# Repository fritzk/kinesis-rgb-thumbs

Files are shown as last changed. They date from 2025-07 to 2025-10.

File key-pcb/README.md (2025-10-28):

# Single-Switch SMD RGB PCB
A compact PCB designed to add individual, addressable SMD RGB lighting to a single mx mechanical keyboard switch.

---

## Features

* **Compact Footprint:** Minimal size, smaller than 1U
* **Chainable:** Data in/out for LED on either side of board
* **Addressable RGB:** Designed for **SK6812MINI-E** leds 

---

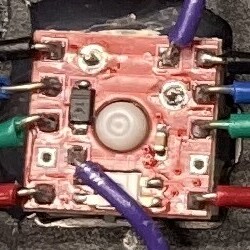
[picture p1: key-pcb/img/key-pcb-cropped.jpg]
A cropped preview of the image


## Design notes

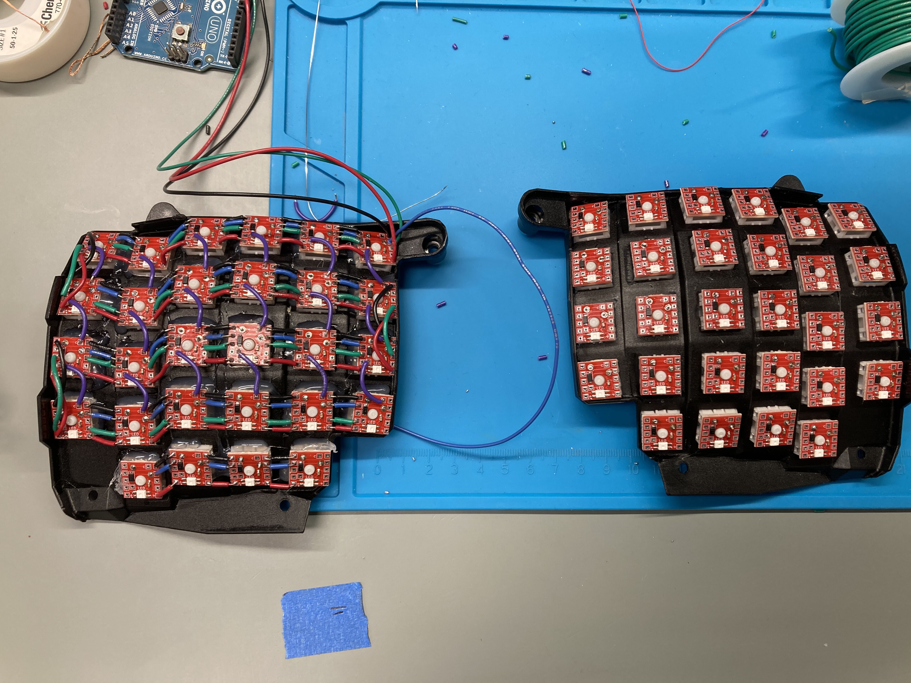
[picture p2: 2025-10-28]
key-pcb/img/key-pcb.jpg

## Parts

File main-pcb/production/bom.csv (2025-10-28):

Designator | Footprint | Quantity | Value | LCSC Part #
H1 | MountingHole_4.3mm_M4_Pad | 1 | mounting pad
J1, J2 | Molex_0039532135 | 2 | Conn_01x13
J10 | PinSocket_1x04_P2.54mm_Vertical | 1 | Conn_01x04
J3 | Molex_KK-254_AE-6410-06A_1x06_P2.54mm_Vertical | 1 | Conn_01x06
J4 | Molex_KK-254_AE-6410-06A_1x06_P2.54mm_Vertical | 1 | Conn_01x06_Pin
J5 | Molex_KK-254_AE-6410-09A_1x09_P2.54mm_Vertical | 1 | Conn_01x09
J6 | Molex_KK-254_AE-6410-09A_1x09_P2.54mm_Vertical | 1 | Conn_01x09_Pin
J7, J8 | PinHeader_1x10_P2.54mm_Vertical | 2 | Conn_01x10_Pin
J9 | PinHeader_1x01_P1.00mm_Vertical | 1 | Conn_01x01
M1 | MountingHole_6.4mm_M6 | 1 | MountingHole_6.4mm_M6
Q1 | SOT-23 | 1 | BSS138
R1, R2 | 0805 | 2 | 10K
U1 | ElitePi | 1 | Elite-Pi

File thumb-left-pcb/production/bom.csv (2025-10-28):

Designator | Footprint | Quantity | Value | LCSC Part #
C25, C35, C36, C46, C55, C56 | 0805 | 6 | 0.1 µF
D25, D35, D36, D46, D55, D56 | D_SOD-123F | 6 | 1N4148WL
J1 | PinHeader_1x10_P2.54mm_Vertical | 1 | Conn_01x10
LED25, LED35, LED36, LED46, LED55, LED56 | LED_MX_6028R | 6 | MX_SK6812MINI-E
MX25, MX35, MX55, MX56 | SW_Cherry_MX_PCB_1.00u | 4 | MX_SW_HS
MX36, MX46 | SW_Cherry_MX_PCB_2.00u_90deg | 2 | MX_SW_HS

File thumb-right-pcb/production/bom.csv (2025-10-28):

Designator | Footprint | Quantity | Value | LCSC Part #
C65, C66, C75, C85, C86, C96 | 0805 | 6 | 0.1 µF
D65, D66, D75, D85, D86, D96 | D_SOD-123F | 6 | 1N4148WL
J1 | PinHeader_1x10_P2.54mm_Vertical | 1 | Conn_01x10
LED65, LED66, LED75, LED85, LED86, LED96 | LED_MX_6028R | 6 | MX_SK6812MINI-E
MX65, MX75 | SW_Cherry_MX_PCB_2.00u_90deg | 2 | MX_SW_HS
MX66, MX85, MX86, MX96 | SW_Cherry_MX_PCB_1.00u | 4 | MX_SW_HS

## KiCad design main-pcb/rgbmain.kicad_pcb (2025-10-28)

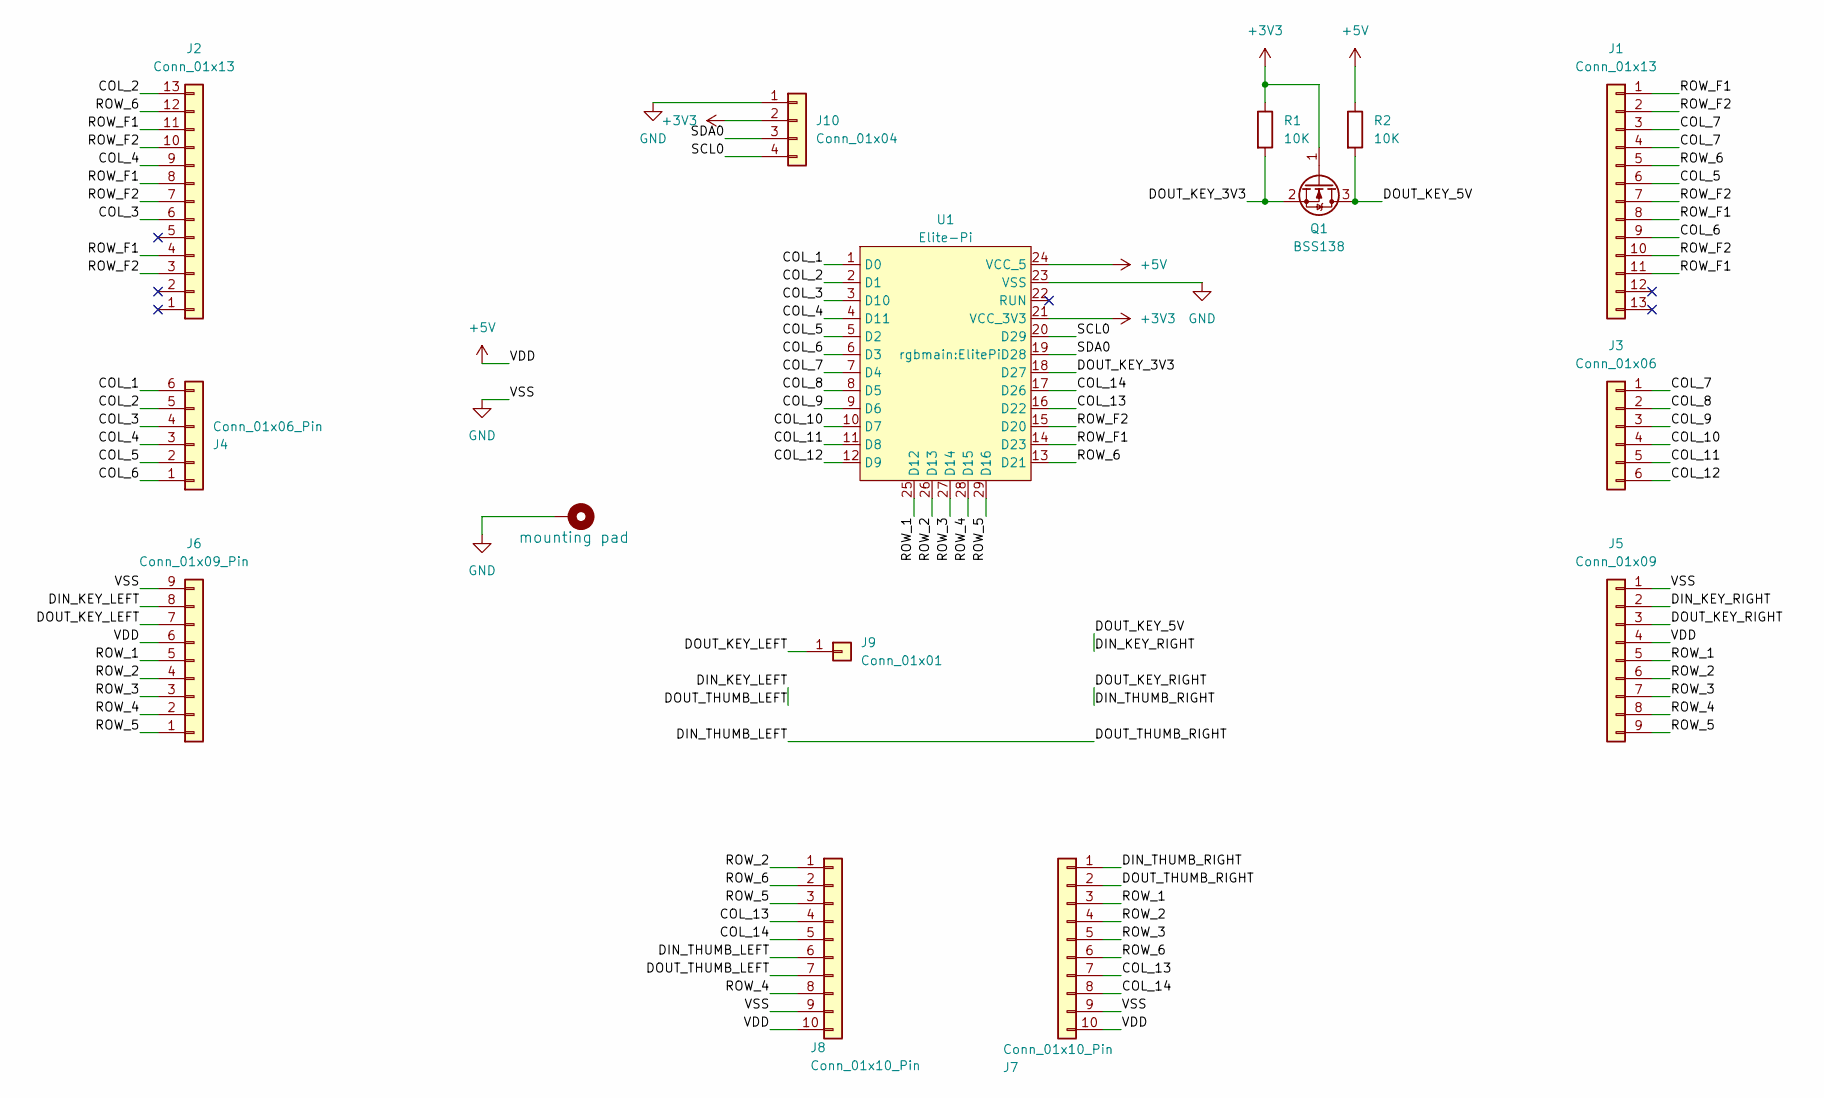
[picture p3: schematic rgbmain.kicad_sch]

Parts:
H1: mounting pad; MountingHole_4.3mm_M4_Pad
J1, J2: Conn_01x13; Molex_0039532135
J3: Conn_01x06; Molex_KK-254_AE-6410-06A_1x06_P2.54mm_Vertical
J4: Conn_01x06_Pin; Molex_KK-254_AE-6410-06A_1x06_P2.54mm_Vertical
J5: Conn_01x09; Molex_KK-254_AE-6410-09A_1x09_P2.54mm_Vertical
J6: Conn_01x09_Pin; Molex_KK-254_AE-6410-09A_1x09_P2.54mm_Vertical
J7, J8: Conn_01x10_Pin; PinHeader_1x10_P2.54mm_Vertical
J9: Conn_01x01; PinHeader_1x01_P1.00mm_Vertical
J10: Conn_01x04; PinSocket_1x04_P2.54mm_Vertical
Q1: BSS138; SOT-23
R1, R2: 10K; R_0805_2012Metric_Pad1.20x1.40mm_HandSolder
U1: Elite-Pi; ElitePi

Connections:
+3V3: J10.2, Q1.1 (G), R1.1, U1.21 (VCC_3V3)
+5V: J5.4, J6.6, J7.10, J8.10, R2.1, U1.24 (VCC_5)
/COL_1: J4.6, U1.1 (D0)
/COL_2: J2.13, J4.5, U1.2 (D1)
/COL_3: J2.6, J4.4, U1.3 (D10)
/COL_4: J2.9, J4.3, U1.4 (D11)
/COL_5: J1.6, J4.2, U1.5 (D2)
/COL_6: J1.9, J4.1, U1.6 (D3)
/COL_7: J1.3, J1.4, J3.1, U1.7 (D4)
/COL_8: J3.2, U1.8 (D5)
/COL_9: J3.3, U1.9 (D6)
/COL_10: J3.4, U1.10 (D7)
/COL_11: J3.5, U1.11 (D8)
/COL_12: J3.6, U1.12 (D9)
/COL_13: J7.7, J8.4, U1.16 (D22)
/COL_14: J7.8, J8.5, U1.17 (D26)
/DIN_KEY_LEFT: J6.8, J8.7
/DIN_KEY_RIGHT: J5.2, Q1.3 (D), R2.2
/DIN_THUMB_LEFT: J7.2, J8.6
/DIN_THUMB_RIGHT: J5.3, J7.1
/DOUT_KEY_3V3: Q1.2 (S), R1.2, U1.18 (D27)
/DOUT_KEY_LEFT: J6.7, J9.1
/ROW_1: J5.5, J6.5, J7.3, U1.25 (D12)
/ROW_2: J5.6, J6.4, J7.4, J8.1, U1.26 (D13)
/ROW_3: J5.7, J6.3, J7.5, U1.27 (D14)
/ROW_4: J5.8, J6.2, J8.8, U1.28 (D15)
/ROW_5: J5.9, J6.1, J8.3, U1.29 (D16)
/ROW_6: J1.5, J2.12, J7.6, J8.2, U1.13 (D21)
/ROW_F1: J1.1, J1.8, J1.11, J2.4, J2.8, J2.11, U1.14 (D23)
/ROW_F2: J1.2, J1.7, J1.10, J2.3, J2.7, J2.10, U1.15 (D20)
/SCL0: J10.4, U1.20 (D29)
/SDA0: J10.3, U1.19 (D28)
GND: H1.1, J5.1, J6.9, J7.9, J8.9, J10.1, U1.23 (VSS)

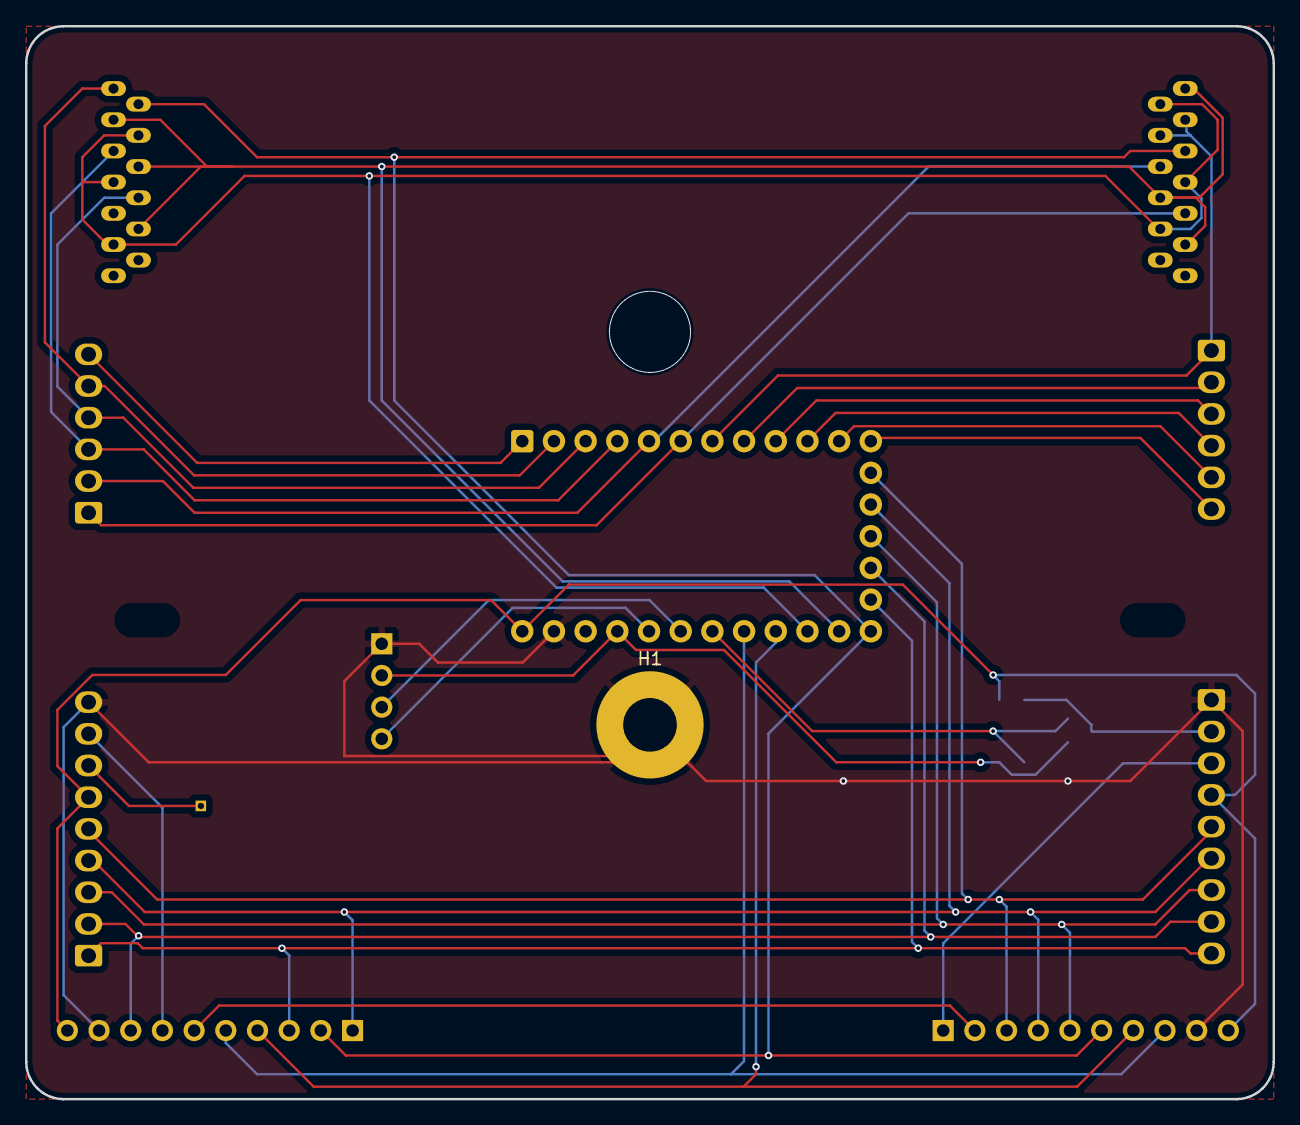
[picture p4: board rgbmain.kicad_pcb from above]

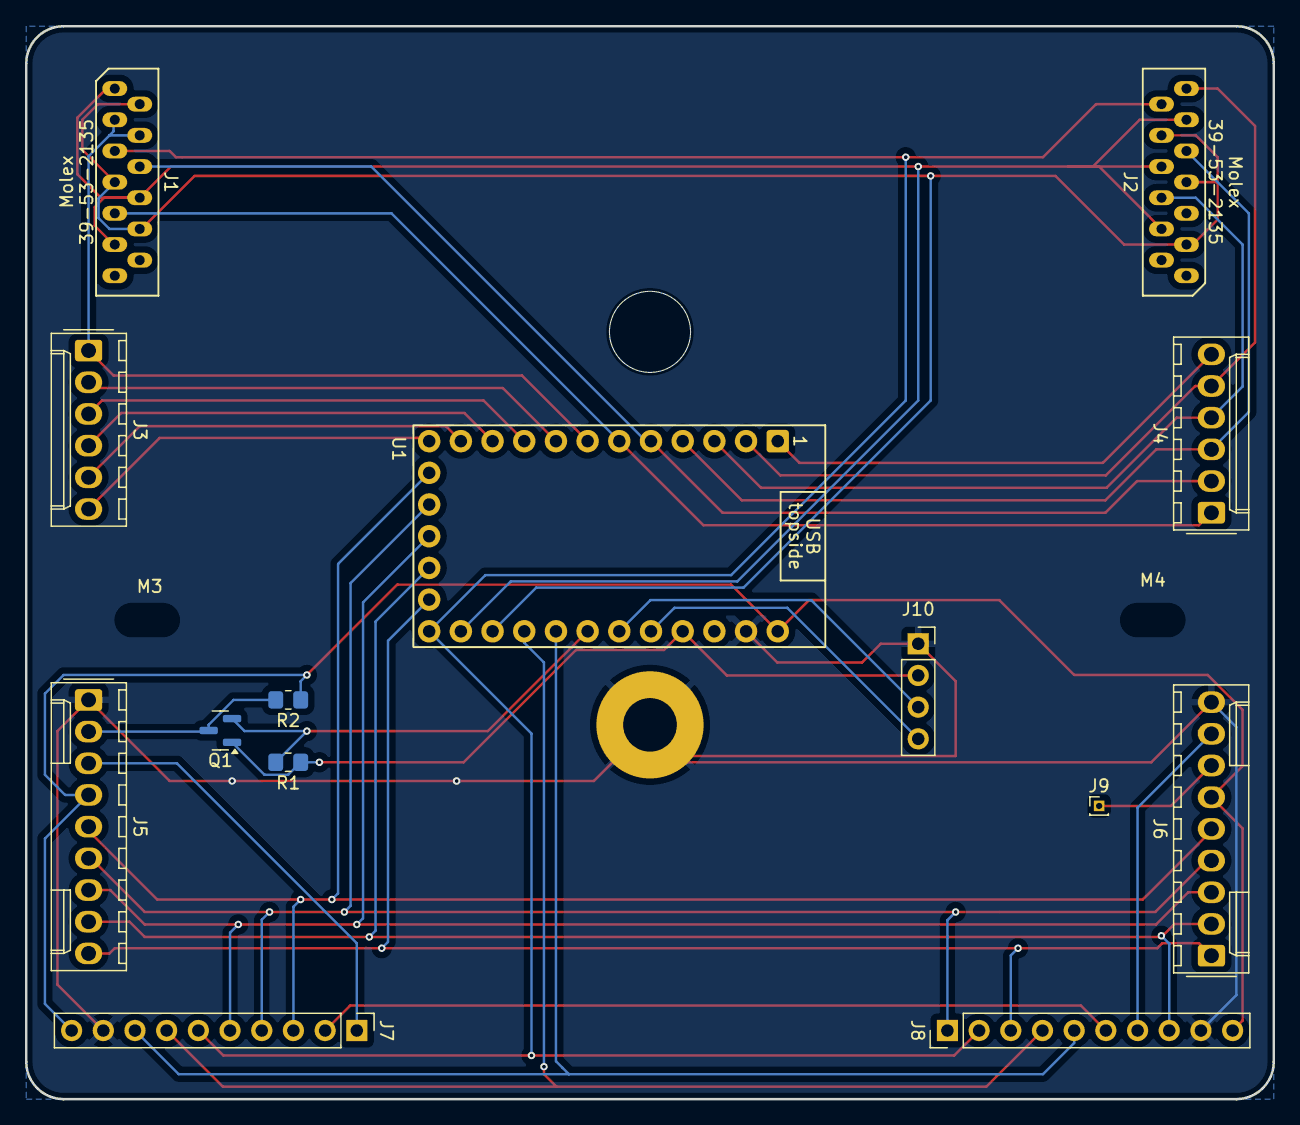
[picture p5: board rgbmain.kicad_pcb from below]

Board: 2 copper layers, 100.0 x 86.0 mm, 18 parts (17 on the bottom side), 33 nets.

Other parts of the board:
M1: MountingHole_6.4mm_M6
M3, M4: MountingHole_4.3mm_M4

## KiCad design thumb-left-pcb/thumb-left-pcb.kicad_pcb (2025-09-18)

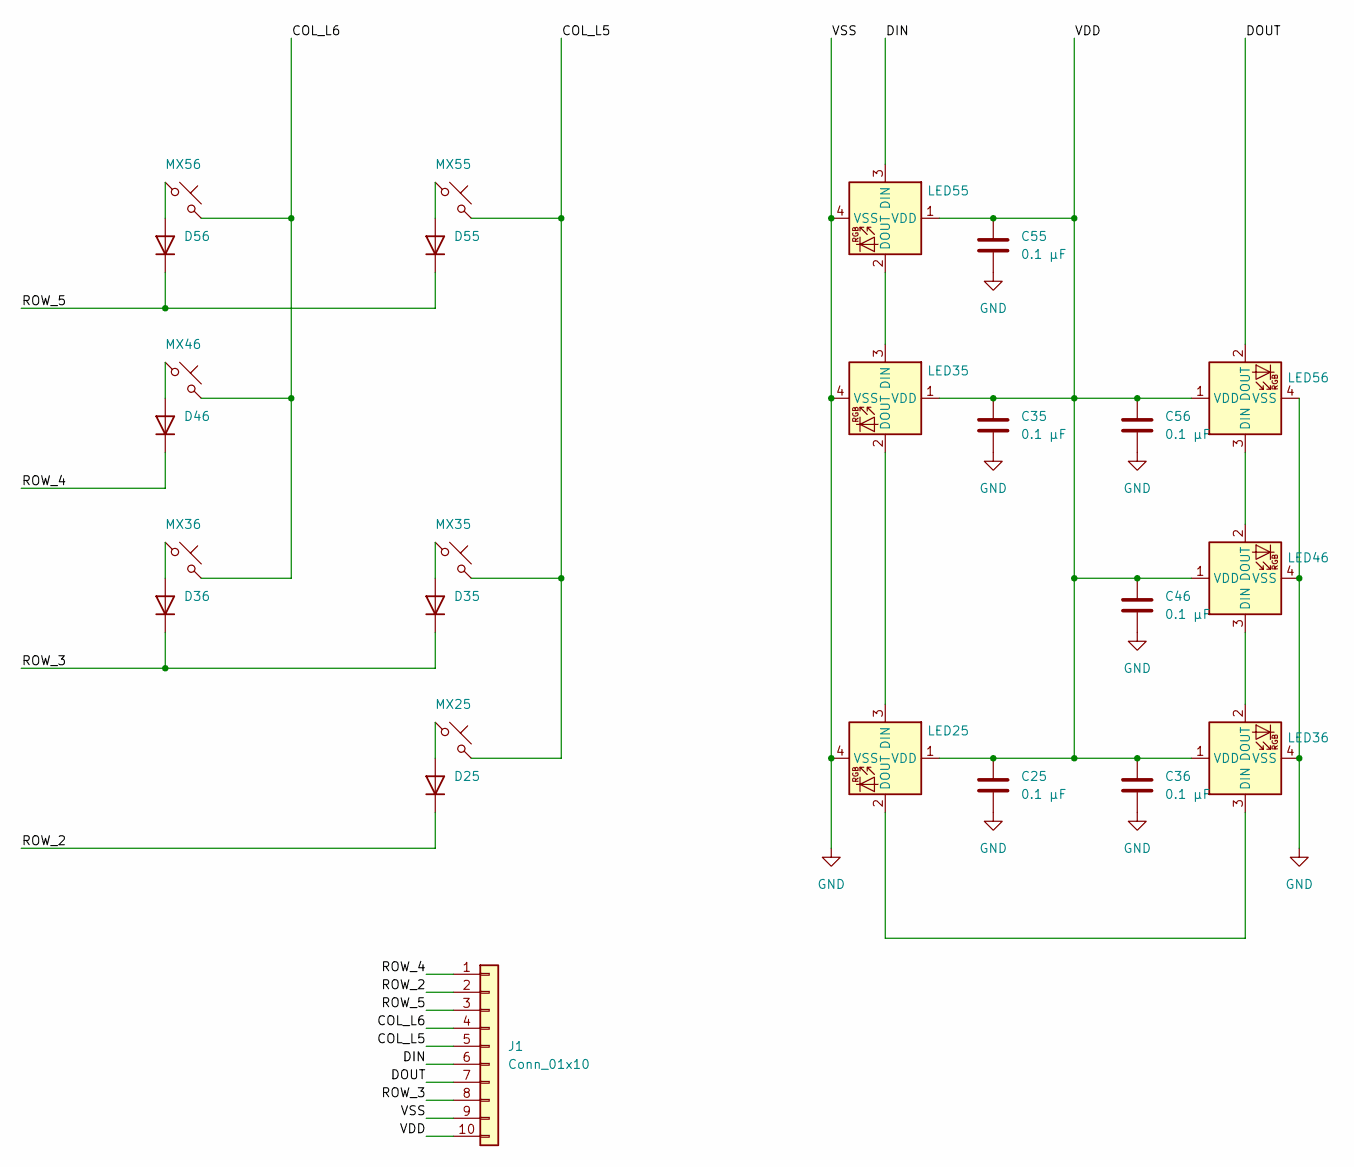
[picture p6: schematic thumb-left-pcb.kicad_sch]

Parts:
C25, C35, C36, C46, C55, C56: 0.1 µF; C_0805_2012Metric_Pad1.18x1.45mm_HandSolder
D25, D35, D36, D46, D55, D56: 1N4148WL; D_SOD-123F
J1: Conn_01x10; PinHeader_1x10_P2.54mm_Vertical
LED25, LED35, LED36, LED46, LED55, LED56: MX_SK6812MINI-E; LED_MX_6028R
MX25, MX35, MX55, MX56: MX_SW_HS; SW_Cherry_MX_PCB_1.00u
MX36, MX46: MX_SW_HS; SW_Cherry_MX_PCB_2.00u_90deg

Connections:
/COL_L5: J1.5, MX25.2, MX35.2, MX55.2
/COL_L6: J1.4, MX36.2, MX46.2, MX56.2
/DIN: J1.6, LED55.3 (DIN)
/DOUT: J1.7, LED56.2 (DOUT)
/ROW_2: D25.1 (K), J1.2
/ROW_3: D35.1 (K), D36.1 (K), J1.8
/ROW_4: D46.1 (K), J1.1
/ROW_5: D55.1 (K), D56.1 (K), J1.3
/VDD: C25.1, C35.1, C36.1, C46.1, C55.1, C56.1, J1.10, LED25.1 (VDD), LED35.1 (VDD), LED36.1 (VDD), LED46.1 (VDD), LED55.1 (VDD), LED56.1 (VDD)
GND: C25.2, C35.2, C36.2, C46.2, C55.2, C56.2, J1.9, LED25.4 (VSS), LED35.4 (VSS), LED36.4 (VSS), LED46.4 (VSS), LED55.4 (VSS), LED56.4 (VSS)
unnamed: D25.2 (A), MX25.1
unnamed: D35.2 (A), MX35.1
unnamed: D36.2 (A), MX36.1
unnamed: D46.2 (A), MX46.1
unnamed: D55.2 (A), MX55.1
unnamed: D56.2 (A), MX56.1
unnamed: LED25.3 (DIN), LED35.2 (DOUT)
unnamed: LED25.2 (DOUT), LED36.3 (DIN)
unnamed: LED35.3 (DIN), LED55.2 (DOUT)
unnamed: LED36.2 (DOUT), LED46.3 (DIN)
unnamed: LED46.2 (DOUT), LED56.3 (DIN)

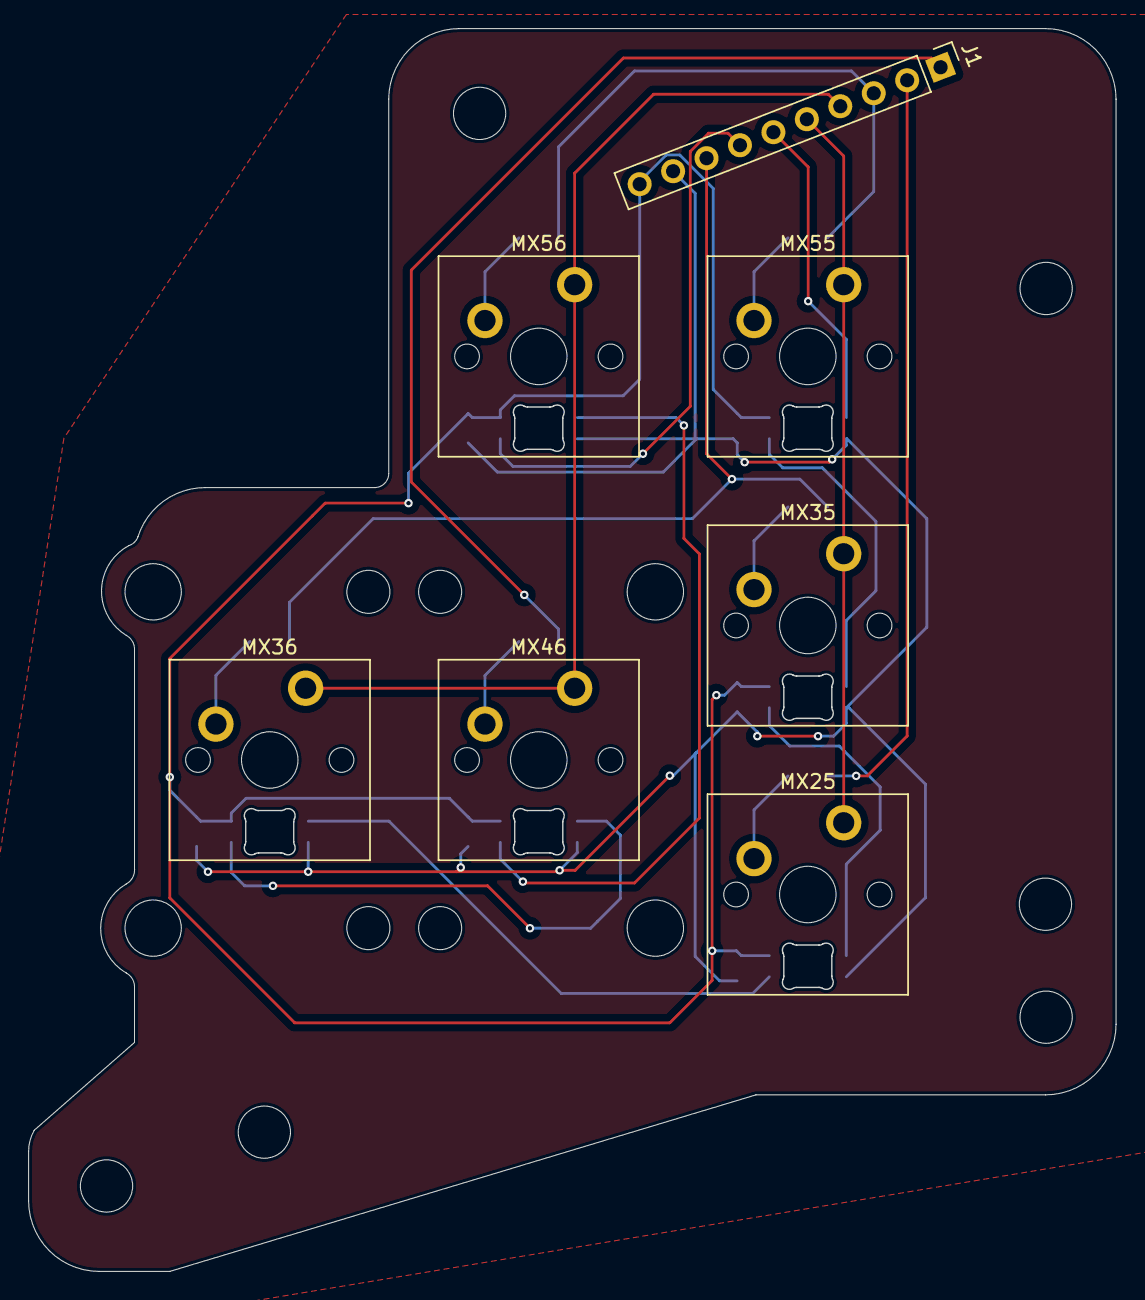
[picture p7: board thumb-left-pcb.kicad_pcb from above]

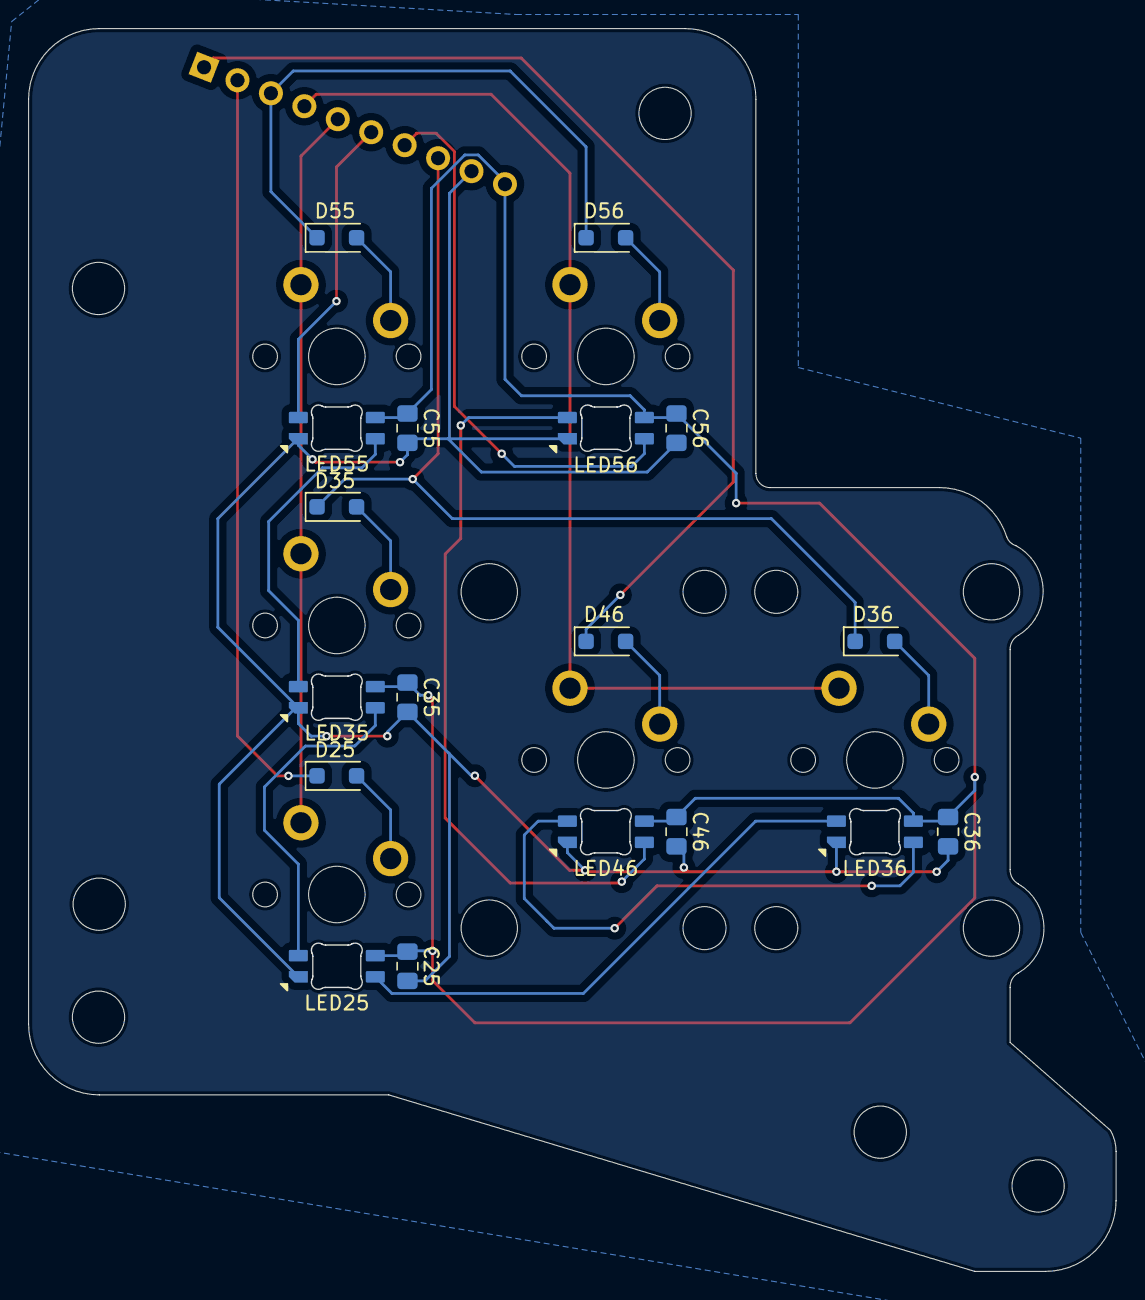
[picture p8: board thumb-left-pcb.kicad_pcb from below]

Board: 2 copper layers, 77.0 x 88.0 mm, 31 parts (18 on the bottom side), 21 nets.

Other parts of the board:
REF1, REF2, REF3, REF4, REF5, REF6: MountingHole_3.7mm

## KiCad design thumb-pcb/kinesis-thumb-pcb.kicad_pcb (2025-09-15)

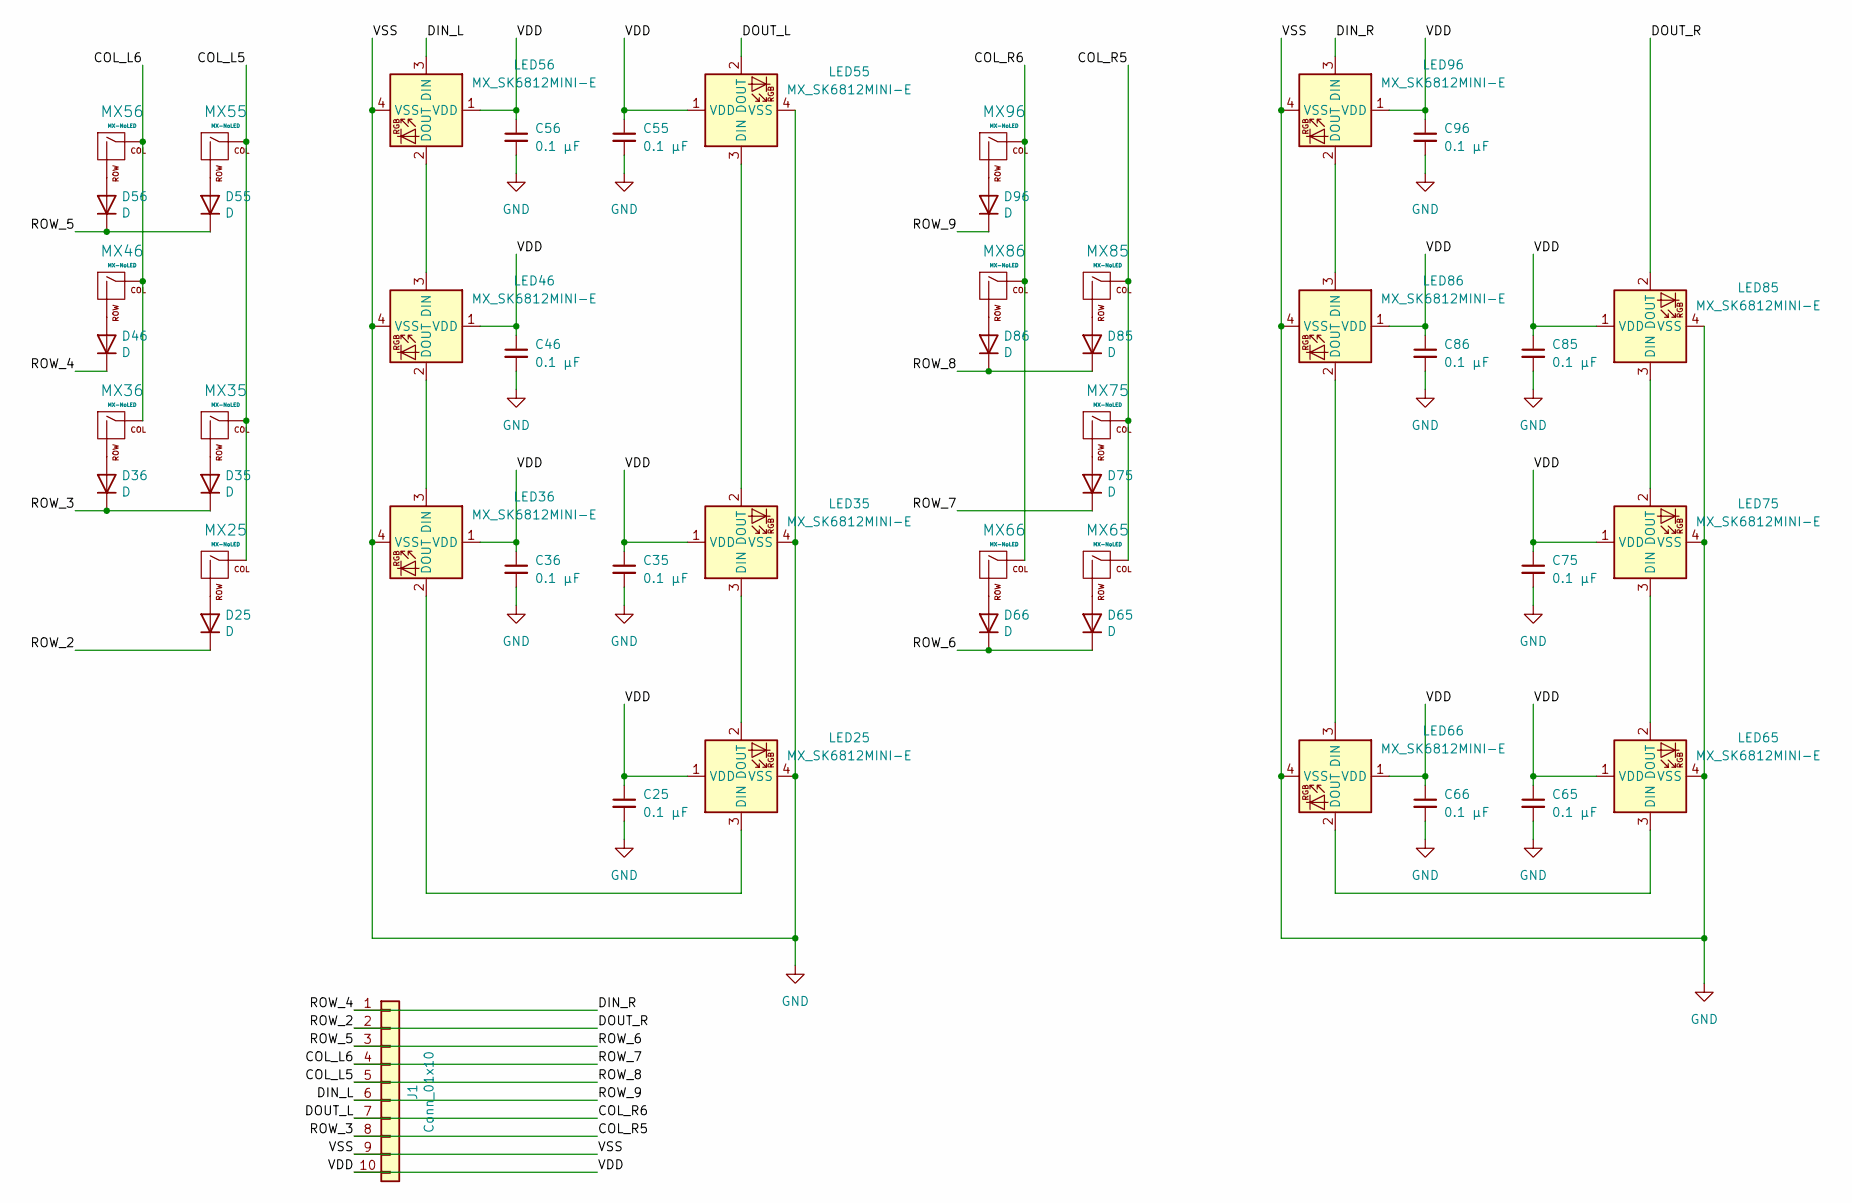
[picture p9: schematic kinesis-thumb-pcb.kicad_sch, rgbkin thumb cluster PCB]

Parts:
C25, C35, C36, C46, C55, C56, C65, C66, C75, C85, C86, C96: 0.1 µF; C_0805_2012Metric_Pad1.18x1.45mm_HandSolder
D25, D35, D36, D46, D55, D56, D65, D66, D75, D85, D86, D96: D; D_SOD-323_HandSoldering
J1: Conn_01x10; Pin_Header_Straight_1x10_Pitch2.54mm
LED25, LED35, LED36, LED46, LED55, LED56, LED65, LED66, LED75, LED85, LED86, LED96: MX_SK6812MINI-E; LED_MX_6028R
MX25, MX35, MX36, MX46, MX55, MX56, MX65, MX66, MX75, MX85, MX86, MX96: MX-NoLED

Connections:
/COL_L5: D85.1 (K), D86.1 (K), J1.5, MX25.1 (COL), MX35.1 (COL), MX55.1 (COL)
/COL_L6: D75.1 (K), J1.4, MX36.1 (COL), MX46.1 (COL), MX56.1 (COL)
/COL_R5: D35.1 (K), D36.1 (K), J1.8, MX65.1 (COL), MX75.1 (COL), MX85.1 (COL)
/COL_R6: J1.7, LED55.2 (DOUT), MX66.1 (COL), MX86.1 (COL), MX96.1 (COL)
/DIN_L: D96.1 (K), J1.6, LED56.3 (DIN)
/DIN_R: D46.1 (K), J1.1, LED96.3 (DIN)
/DOUT_R: D25.1 (K), J1.2, LED85.2 (DOUT)
/ROW_5: D55.1 (K), D56.1 (K), D65.1 (K), D66.1 (K), J1.3
/VDD: C25.1, C35.1, C36.1, C46.1, C55.1, C56.1, C65.1, C66.1, C75.1, C85.1, C86.1, C96.1, J1.10, LED25.1 (VDD), LED35.1 (VDD), LED36.1 (VDD), LED46.1 (VDD), LED55.1 (VDD), LED56.1 (VDD), LED65.1 (VDD), LED66.1 (VDD), LED75.1 (VDD), LED85.1 (VDD), LED86.1 (VDD), LED96.1 (VDD)
GND: C25.2, C35.2, C36.2, C46.2, C55.2, C56.2, C65.2, C66.2, C75.2, C85.2, C86.2, C96.2, J1.9, LED25.4 (VSS), LED35.4 (VSS), LED36.4 (VSS), LED46.4 (VSS), LED55.4 (VSS), LED56.4 (VSS), LED65.4 (VSS), LED66.4 (VSS), LED75.4 (VSS), LED85.4 (VSS), LED86.4 (VSS), LED96.4 (VSS)
unnamed: D25.2 (A), MX25.2 (ROW)
unnamed: D35.2 (A), MX35.2 (ROW)
unnamed: D36.2 (A), MX36.2 (ROW)
unnamed: D46.2 (A), MX46.2 (ROW)
unnamed: D55.2 (A), MX55.2 (ROW)
unnamed: D56.2 (A), MX56.2 (ROW)
unnamed: D65.2 (A), MX65.2 (ROW)
unnamed: D66.2 (A), MX66.2 (ROW)
unnamed: D75.2 (A), MX75.2 (ROW)
unnamed: D85.2 (A), MX85.2 (ROW)
unnamed: D86.2 (A), MX86.2 (ROW)
unnamed: D96.2 (A), MX96.2 (ROW)
unnamed: LED25.3 (DIN), LED36.2 (DOUT)
unnamed: LED25.2 (DOUT), LED35.3 (DIN)
unnamed: LED35.2 (DOUT), LED55.3 (DIN)
unnamed: LED36.3 (DIN), LED46.2 (DOUT)
unnamed: LED46.3 (DIN), LED56.2 (DOUT)
unnamed: LED65.3 (DIN), LED66.2 (DOUT)
unnamed: LED65.2 (DOUT), LED75.3 (DIN)
unnamed: LED66.3 (DIN), LED86.2 (DOUT)
unnamed: LED75.2 (DOUT), LED85.3 (DIN)
unnamed: LED86.3 (DIN), LED96.2 (DOUT)

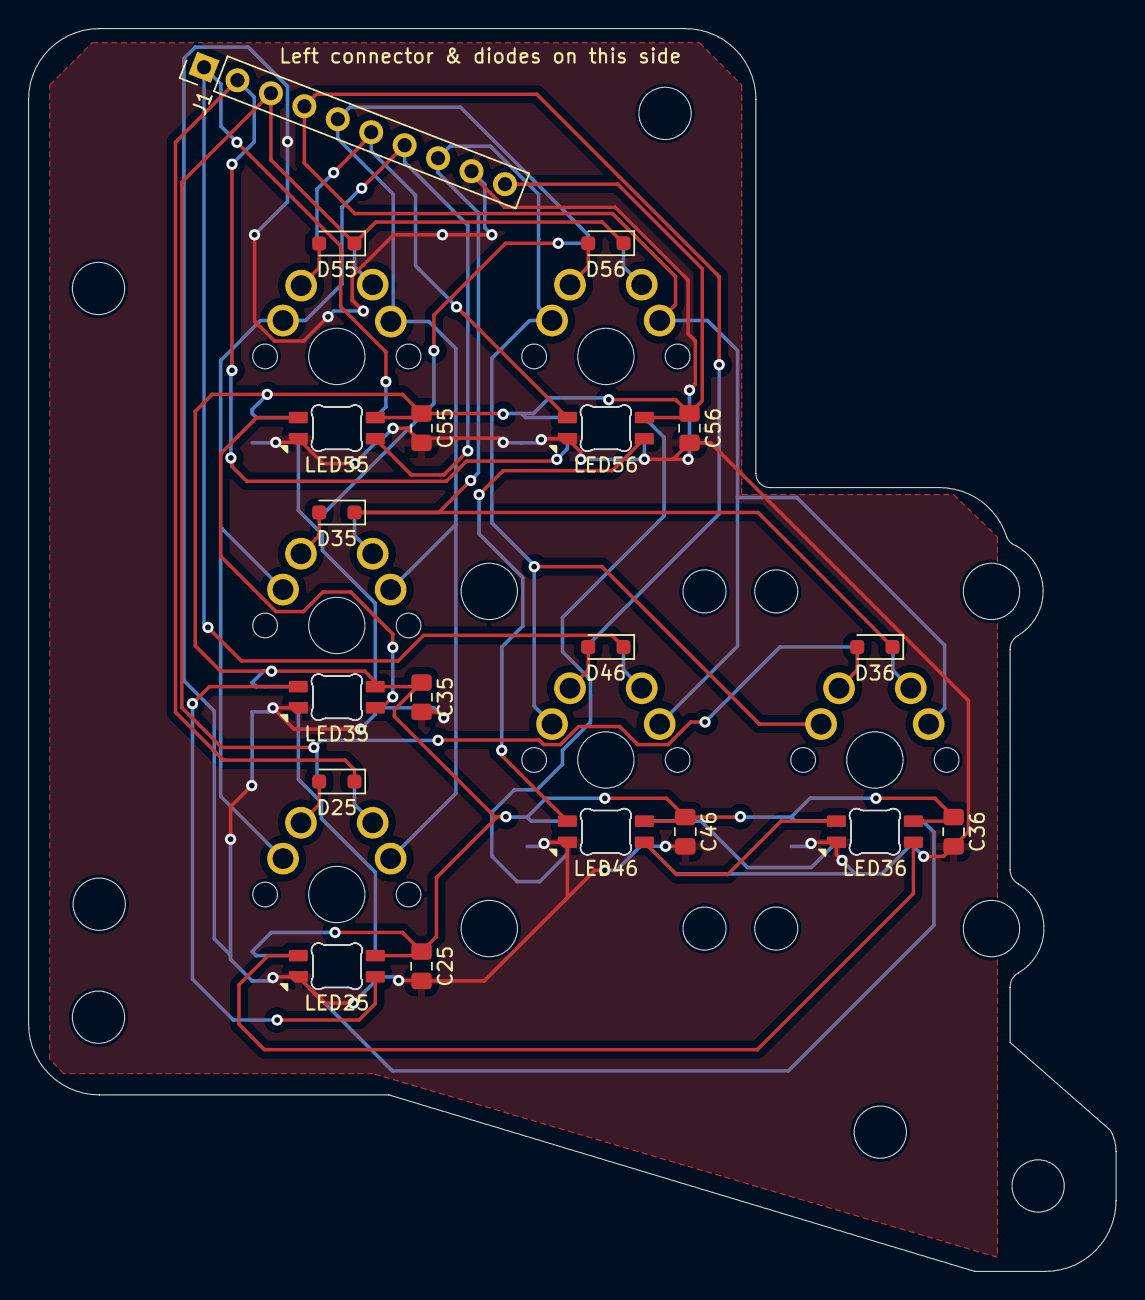
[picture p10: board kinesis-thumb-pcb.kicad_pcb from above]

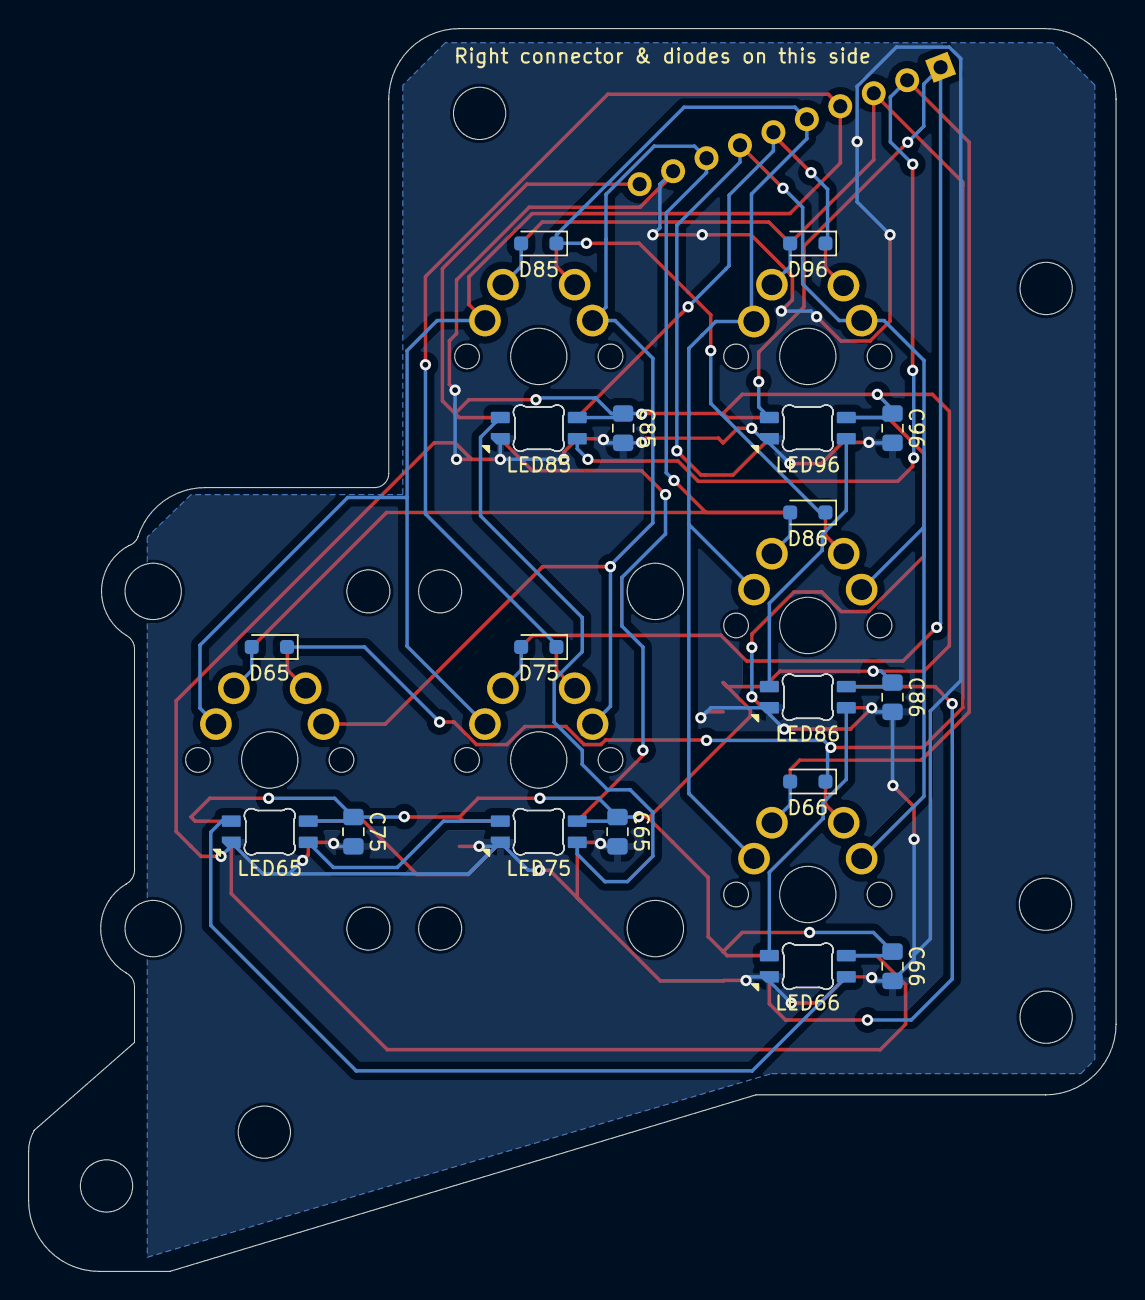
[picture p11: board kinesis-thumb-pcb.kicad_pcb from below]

Board: 2 copper layers, 77.0 x 88.0 mm, 55 parts (30 on the bottom side), 32 nets.

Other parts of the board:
REF1, REF2, REF3, REF4, REF5, REF6: MountingHole_3.7mm

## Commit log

2025-05-26 Start of per key pcb
    [key-pcb.kicad_pcb, key-pcb.kicad_sch]
2025-05-26 Schematics for per key pcb done
    [key-pcb.kicad_sch]
2025-05-26 First attempt at layout. Not good.
    Pins are too close together and won't fit on board.
    [key-pcb.kicad_pcb, key-pcb.kicad_sch]
2025-05-27 Routed, but DRC violation
    [key-pcb.kicad_pcb, key-pcb.kicad_sch]
2025-05-31 Passing all DRC
    [key-pcb.kicad_pcb]
2025-05-31 Smaller board
    [key-pcb.kicad_pcb]
2025-05-31 Ground fill
    [key-pcb.kicad_pcb]
2025-05-31 Passing JLCPCB rules (but some warnings)
    [key-pcb.kicad_pcb]
2025-05-31 Gerber creation options
    [key-pcb.kicad_pcb]
2025-08-30 Imported from https://github.com/dcpedit/pillzmod
    [kinesis-thumb-pcb.kicad_pcb, kinesis-thumb-pcb.kicad_sch, kinesis-thumb-pcb.sch]
2025-08-31 Part placement
    [kinesis-thumb-pcb.kicad_pcb, kinesis-thumb-pcb.kicad_sch]
2025-08-31 Checkpoint - routing
    [kinesis-thumb-pcb.kicad_pcb]
2025-08-31 SOD123 Diodes
    [kinesis-thumb-pcb.kicad_pcb, kinesis-thumb-pcb.kicad_sch]
2025-08-31 Fully routed
    [kinesis-thumb-pcb.kicad_pcb]
2025-09-15 Left/Right thumb clusters
    Split left and right instead of sharing one pcb.
    [thumb-left-pcb.kicad_pcb, thumb-left-pcb.kicad_sch, thumb-right-pcb.kicad_pcb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]
2025-09-17 Schematic for L/R thumb
    Imported from github.com/dcpedit/pillzmod
    [thumb-left-pcb.kicad_sch, thumb-right-pcb.kicad_sch]
2025-09-17 Ignore temporary/local kicad files
2025-09-17 Update footprints
    [thumb-right-pcb.kicad_sch]
2025-09-17 Component layout
    [thumb-right-pcb.kicad_pcb]
2025-09-17 Switch and diodes fully routed
    [thumb-right-pcb.kicad_pcb]
2025-09-17 Update capacitor footprint
    Use the hand solder pads.
    [thumb-right-pcb.kicad_pcb]
2025-09-17 Updated design rules
    JLPCB rules + pad to edge for led cutouts
2025-09-17 Update silk for DRC
    [thumb-right-pcb.kicad_pcb]
2025-09-17 Fill all zones
    [thumb-right-pcb.kicad_pcb]
2025-09-17 left thumb starting pcb
    Copy in right and flip.
    [thumb-left-pcb.kicad_pcb]
2025-09-17 update left footprints
    [thumb-left-pcb.kicad_sch]
2025-09-17 rework left-thumb schematic
    The uuid's match up so that when the pcb is layed out
    the right can be used as a starting point.
    [thumb-left-pcb.kicad_sch]
2025-09-17 sync left schematic with pcb
    [thumb-left-pcb.kicad_pcb]
2025-09-17 move components to correct side
    [thumb-left-pcb.kicad_pcb]
2025-09-17 update copper edge clearance for left pcb
2025-09-17 left complete with fill
    [thumb-left-pcb.kicad_pcb]
2025-09-18 added 2u stabilizers
    [thumb-left-pcb.kicad_pcb, thumb-right-pcb.kicad_pcb]
2025-09-18 left D25 flipped
    [thumb-left-pcb.kicad_pcb]
2025-09-18 fixed net names for left thumb columns
    [thumb-left-pcb.kicad_sch]
2025-09-18 fix left thumb nets
    [thumb-left-pcb.kicad_sch]
2025-09-18 left thumb routed
    [thumb-left-pcb.kicad_pcb]
2025-10-13 remove key-pcb
    moved to it's own repo
    [key-pcb.kicad_pcb, key-pcb.kicad_sch]
2025-10-18 initialize kicad
    [rgbmain.kicad_pcb, rgbmain.kicad_sch]
2025-10-18 initial pin labeling
    [rgbmain.kicad_sch]
2025-10-19 right side connectors were rotated incorrectly
    [rgbmain.kicad_sch]
2025-10-19 symbol for Elite-Pi added
    [rgbmain.kicad_sch]
2025-10-19 wire mcu up
    [rgbmain.kicad_sch]
2025-10-22 elite-pi footprint
2025-10-22 changed number to match footprint
    [rgbmain.kicad_sch]
2025-10-22 molex function key header
    copied from: https://github.com/dcpedit/pillzmod/blob/main/pcb-pro/kinesisMod_board_connectors.pretty/Molex_0039532135.kicad_mod
2025-10-22 footprints added
    [rgbmain.kicad_sch]
2025-10-22 use the Molex KK *2.54*
    footprints sourced from: https://github.com/SnowMB/pcb_library
    [rgbmain.kicad_sch]
2025-10-22 use vertical pcb connectors
    horizontal take up too much board space
    [rgbmain.kicad_sch]
2025-10-22 initial pcb placement
    [rgbmain.kicad_pcb]
2025-10-26 wired up all function keys
    [rgbmain.kicad_sch]
2025-10-26 pcb layout complete
    [rgbmain.kicad_pcb, rgbmain.kicad_sch]
2025-10-27 changed thumb connectors
    wanted thumbs to be the same as stock.
    [rgbmain.kicad_pcb, rgbmain.kicad_sch]
2025-10-27 more connector flipping
    [rgbmain.kicad_pcb]
2025-10-28 sent out for fabrication
    [bom.csv, designators.csv, positions.csv]
2025-10-28 prepare main for single repo
    [bom.csv, designators.csv, positions.csv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]
2025-10-28 prepare key for single repo
    [key-pcb.kicad_pcb, key-pcb.kicad_sch]
2025-10-28 normalize names
    [bom.csv, designators.csv, positions.csv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]
